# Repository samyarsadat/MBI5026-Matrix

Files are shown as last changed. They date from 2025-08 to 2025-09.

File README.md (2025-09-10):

# MBI5026 16x40 LED Display
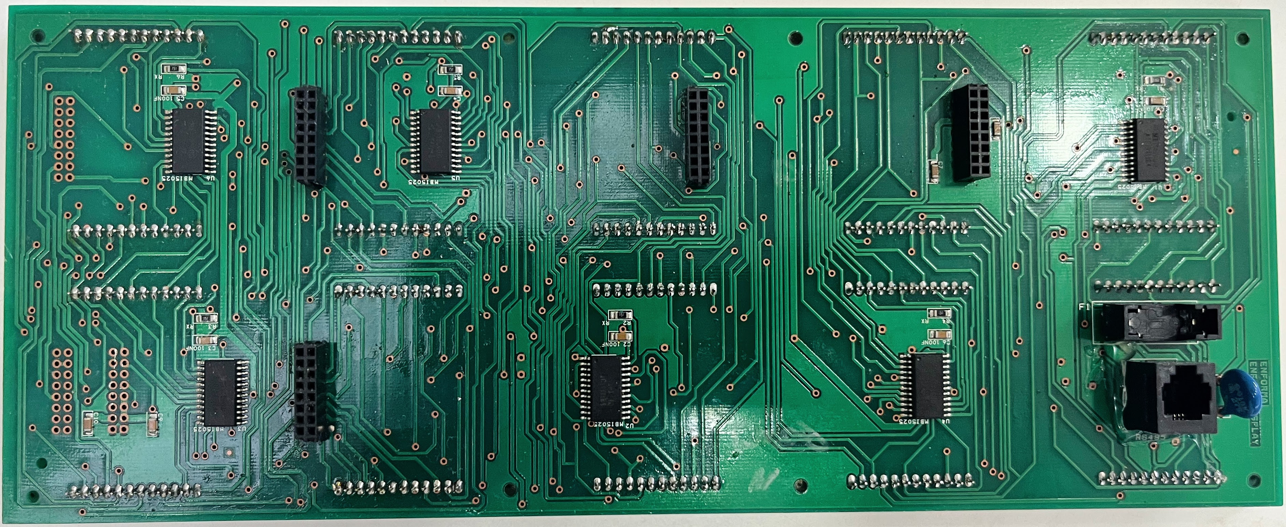
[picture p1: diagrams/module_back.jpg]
back of display module

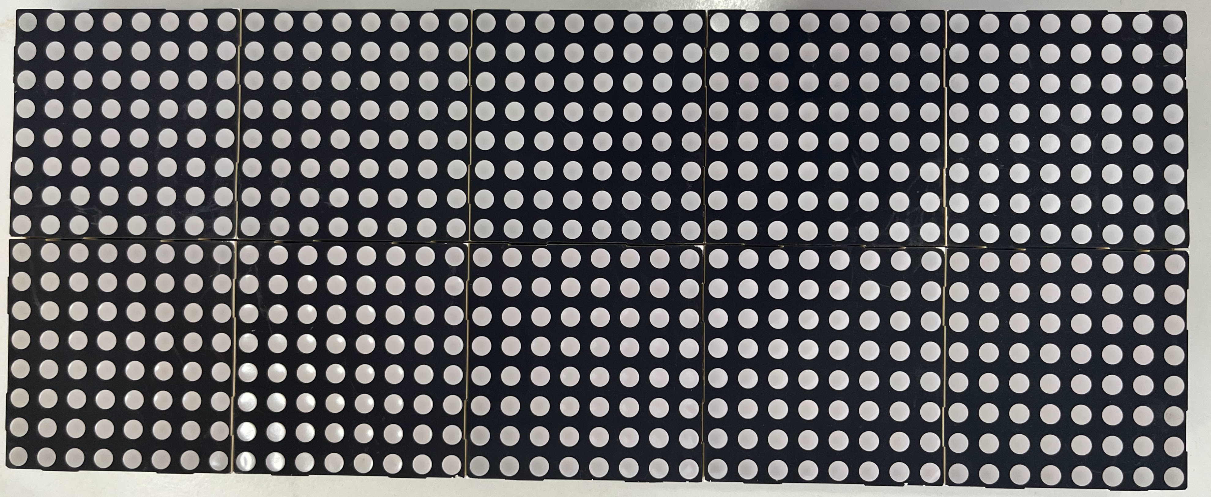
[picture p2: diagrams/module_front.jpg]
front of display module


In November 2023, I got my hands on a number of 16x40 LED matrix displays produced by a company called "Enforma". There was no documentation provided with these displays, but they had RJ-11 connectors on their backs labeled `RS485`. This gave me hope, at first, as it implied that no driver circuitry was needed and that I only needed to send data to the displays over a serial connection.

<p align="center">
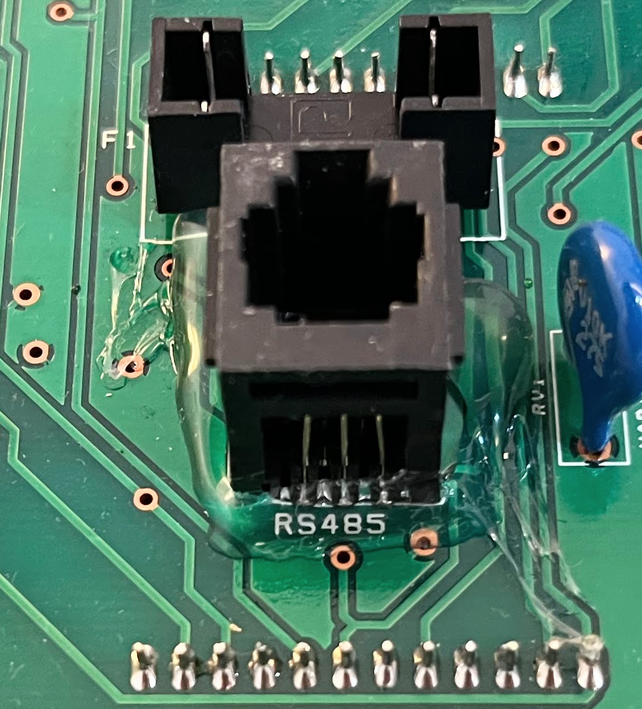
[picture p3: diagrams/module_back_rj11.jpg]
  
</p>

Upon closer inspection, I found 6 ICs on the matrix PCBs. They were all labeled `MBI5026GD`. After a quick Google search, I was able to find their datasheet. According to the datasheet, the `MBI5026` is a "16-bit constant-current LED sink driver". This tells us a lot about what these chips do, and it also indicated to me that there must be some kind of external control circuitry somewhere, but we will get to that later.

<br>

## The MBI5026
An LED sink driver (or current-sink driver) is one of two main LED driver types (the other being source/current-source drivers). Electrical current is "sunk" to these drivers, as the name might suggest (the direction of electron flow is from negative to positive, but I am referring to current flow), and so their outputs are connected to the cathodes of the LEDs. The `MBI5026`, specifically, is also a constant-current LED driver, which means that it keeps the current flowing through the LEDs constant, regardless of the LED's bias voltage (the current is set using an external resistor attached to a dedicated pin on the IC).

Another important feature of these ICs is that they handle inputs serially, similar to a shift register. This makes it rather simple for them to be daisy-chained (as they are in this matrix), and it allows for a clever optimization when it comes to sending data to them using microcontrollers. The optimization in question is using the built-in SPI hardware to send data instead of bit-banging. This allows for data to be sent at much higher rates and, of course, frees up many CPU cycles, something we need a lot of.

The LED matrix modules here are configured such that the cathodes of the LEDs are all attached to each other in columns. This means that our `MBI5026` ICs control the columns of the module. So the cathodes of all 16 LEDs in each column are connected to one output on one of the three (per color - one set for red, one set for green) `MBI5026`s.

I haven't mentioned it until now, but yes, these displays use dual-color LED matrices (red and green). That is why we have 6 `MBI5026`s instead of 3 (3 * 16 = 48 outputs, which would've been enough for a single color, as the display only has 40 columns). Each group of 3 is responsible for one color. The LEDs are wired-up as shown below:

<p align="center">
  
</p>

Okay, now we can control the columns, but what about the rows? Well... that’s where things get a little bit more complicated. I mentioned above that I initially thought no extra control circuitry was needed for the displays, but that I was mistaken. Well, let me explain why that is case.

After finding out what the `MBI5026`s were, I tried to look for some type of current-source driver for the anodes of the LEDs, but I found none. Instead, I managed to trace the anodes of the displays to a pair of headers on the back of the PCB. I then also traced two of the pins (data pins, as the other two were connected to GND and VCC) of the aforementioned RJ-11 connector to another header, and the data, clock, and latch pins of the `MBI5026`s to a fourth header.

These discoveries made it clear to me that there must have been some kind of control board attached to these display PCBs using those four connectors, and that that board contained the rest of the circuitry required for making the displays work.

<br>

## Driving the Displays
### Hardware
> [!NOTE]
> The displays are designed to operate at +5V DC, which is also the nominal operating voltage of the `MBI5026`. The operating voltage for all other components mentioned here is also +5V DC.

With all of this information in hand, I devised a simple circuit to drive these displays using the Arduino UNO R3 (ATMega328P). The circuit consists of 16 P-channel MOSFETs for driving the anodes of the matrices. As mentioned before, the anodes of the displays are linked together in rows, and these displays have 16 rows; hence, we need 16 MOSFETs.

Now, after we consider the `MBI5026` connections, we aren't left with the 16 pins we need to drive the MOSFETs, but we also don't really need 16 pins. It would be a waste to connect all MOSFETs directly, as we don't need to be able to activate more than one MOSFET at once, instead, we can use a 16-channel multiplexer.

I chose the `74HC4067`, as it's one I'm already familiar with, and it has decent specifications for this application. The `74HC4067` is a 16-channel analog multiplexer, but any 16-channel mux with good enough switching characteristics will do just fine; it doesn't even have to be an analog mux, as we're only controlling MOSFETs.

Most P-channel MOSFETs will also work just fine, you could even use PNP transistors, and you'd probably be fine. As we're multiplexing the rows, each row is only held on for around less than a millisecond (typically, depends on buffer size, and `display_row_on_delay_us`), so there is little continous current draw. The most amount of continuous current draw I observed when holding all pixels in one row on was no more than 400mA.

Note that there are 10k ohm pull-up resistors connected to the gate pins of every MOSFET to ensure that their outputs are turned off when left floating (which is the case, unless they're selected by the mux).

As mentioned before, we'll be using the Arduino's SPI hardware for sending data to the `MBI5026`s. The six `MBI5026`s are divided into two groups of three, one group for red, and the other for green. Note that the anodes for the green and red LEDs are again connected to each other, so we still only need 16 MOSFETs for driving both colors. This works because their cathodes are connected to different `MBI5026`s, of course.

As far as the cathodes are concerned, we can treat the display as two separate displays, one being the green, and the other red. But there's just one problem with this approach... the Arduino UNO R3 only has one set of SPI pins, not two (I have recently been made aware of the SPI over USART mode supported by the ATMega328P, though as you will see, that will not be necessary). The solution to this problem is quite trivial. The `MBI5026`s, in addition to their SDI (Serial Data In) and CLK (Clock) pins, also have an LE (labeled as "Data Strobe Input Terminal" in the datasheet, but I presume it stands for Latch Enable) pin.

You see, data from the input shift register isn't "committed" to the output drivers of the `MBI5026` unless a pulse is sent on the LE pin. This is very handy, as we can connect the SDI and CLK pins of both `MBI5026` groups together, but still maintain the ability to separately control both colors.

<p align="center">
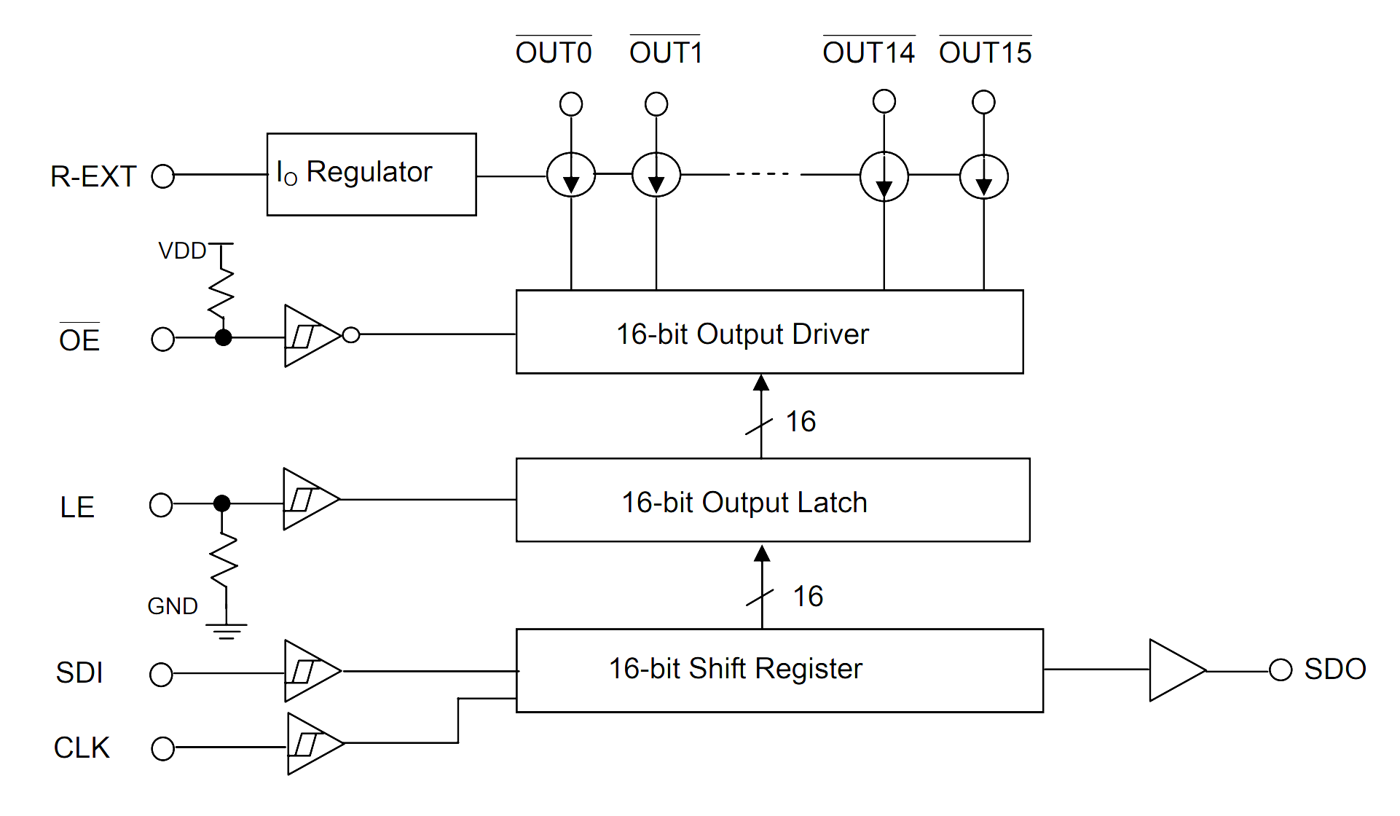
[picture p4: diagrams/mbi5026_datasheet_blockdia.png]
  
</p>

Basically, what we can do is the following:
 - Send the data for the green group over SPI.
 - Pulse the LE pin of the green group, "committing" the desired green pixel states to the output drivers.
 - Send the data for the red group over the same SPI bus.
 - Pulse the LE pin of the red group, "committing" the desired red pixel states to the output drivers.

These steps are repeated for each row, of course, as we are multiplexing the display one-row-at-a-time. More about the software implementation later on.

This is the full circuit diagram I ended up using for testing with the Arduino UNO:

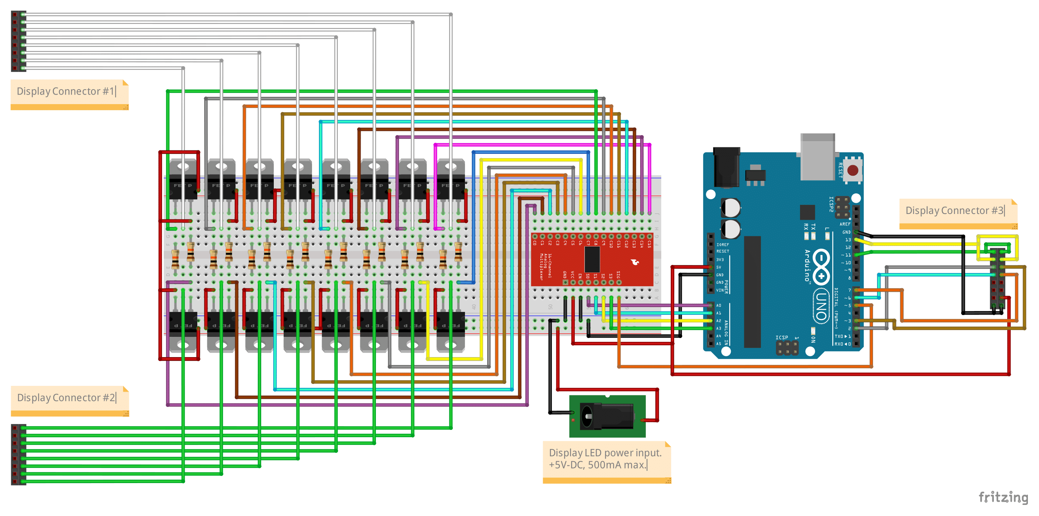
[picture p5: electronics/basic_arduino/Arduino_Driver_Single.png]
basic arduino driver circuit

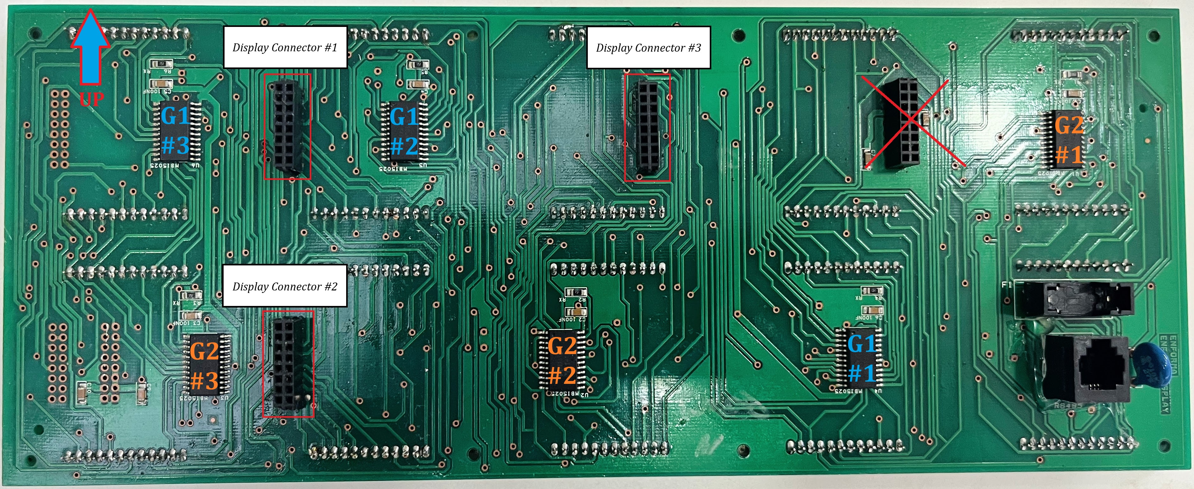
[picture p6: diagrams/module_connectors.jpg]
display module connectors


> [!WARNING]
> A small current may flow through the MOSFET pull-up resistors if the IOREF voltage (IO reference voltage, should be +5V) of the Arduino is different compared to the display LED power input voltage. To avoid this, power the Arduino from the display LED power input as well. Only do this if you don't plan on using the USB port of the Arduino, or are using a diode/MOSFET to OR the power.

> [!NOTE]
> The ground pins on connector #3 are not only logic grounds, but also sink grounds for the `MBI5026`s. Up to 500mA can flow through them (unlikely, but possible), so ensure a good connection to the LED display power supply ground.

<br>
<p align="center">
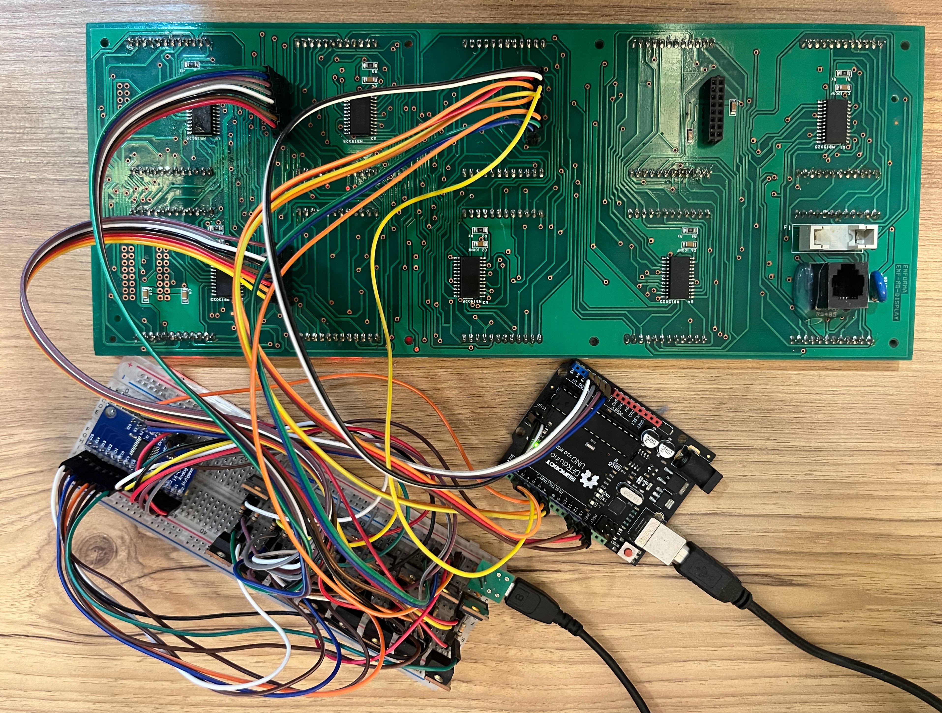
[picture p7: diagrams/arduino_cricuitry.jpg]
  
</p>

> [!NOTE]
> You may have noticed that I'm using the Arduino's ICSP header in this image. The ICSP header also exposes the SPI pins of the ATMega328P, so we can use them for the second `MBI5026` group, as it is more convenient than creating a splitter.

<br>

### Software
The software uses PlatformIO and is written in C++. I opted to use Adafruit's GFX library for text and graphics "rendering" (i.e., generating pixel data from text and/or shape drawing commands, etc.), as I saw no need to implement that myself when there's a perfectly usable and readily available implementation already.

Instead, I focused on optimizing the lower-level details of driving the displays (taking data from a set of pixel buffers, one for red and one for green, and displaying them properly). It was a rather enjoyable experience, as I got to chase down millisecond-level improvements in execution time, which is a level of optimization I often don't or can't pursue.

I will, by no means, claim to have written the _most_ optimized driver for these displays, but I certainly made an attempt, even performing direct register manipulations (I understand the portability implications this comes with, but that really does not matter here) to avoid function call overhead at some points!

In the example I've provided, all of the text "rendering" takes place during the setup phase of the program. This introduces a challenge when one tries to implement scrolling text. Re-rendering the pixel buffer on every scroll cycle is very expensive (CPU cycles-wise, and hence, time-wise) and so results in a lot of flickering.

But why would the display flicker, you may ask. Well, imagine that the pixel data is re-computed every n frames. That means that every n-frames, the frame draw function will take much longer to execute because it needs to re-compute the pixel data. This introduces a (or rather increases the already existing) gap in time where nothing is drawn on the screen, every n frames. That extra delay appears as a flicker every time the display scrolls over by one pixel.

You could simply use a more powerful microcontroller to solve this issue, such as the RP2040/RP2350 from Raspberry Pi or even a microcontroller from the STM32 series (such as the STM32F103, for example), but that would be cheating! Not that this is a competition, but still, what fun would that have been?

So I devised a rather simple solution, one that I'm sure is used in some real LED display drivers as well... We can make our display buffers longer (width-wise) than the size of our actual displays, render the entirety of the contents we want to scroll on the display once at startup (and write it to the buffers, of course), and then simply shift our view of the buffer to the right by one pixel every n-milliseconds when actually displaying the contents on the screen.

Below, you can see some diagrams explaining one full scroll cycle, as implemented right now.

<br>

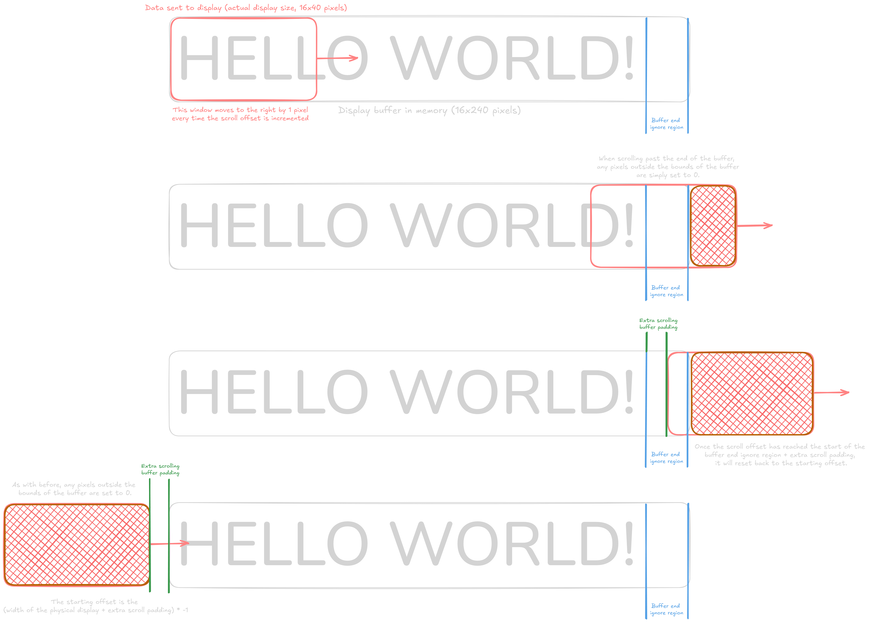
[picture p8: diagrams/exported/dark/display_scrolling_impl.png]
scrolling implementation diagram

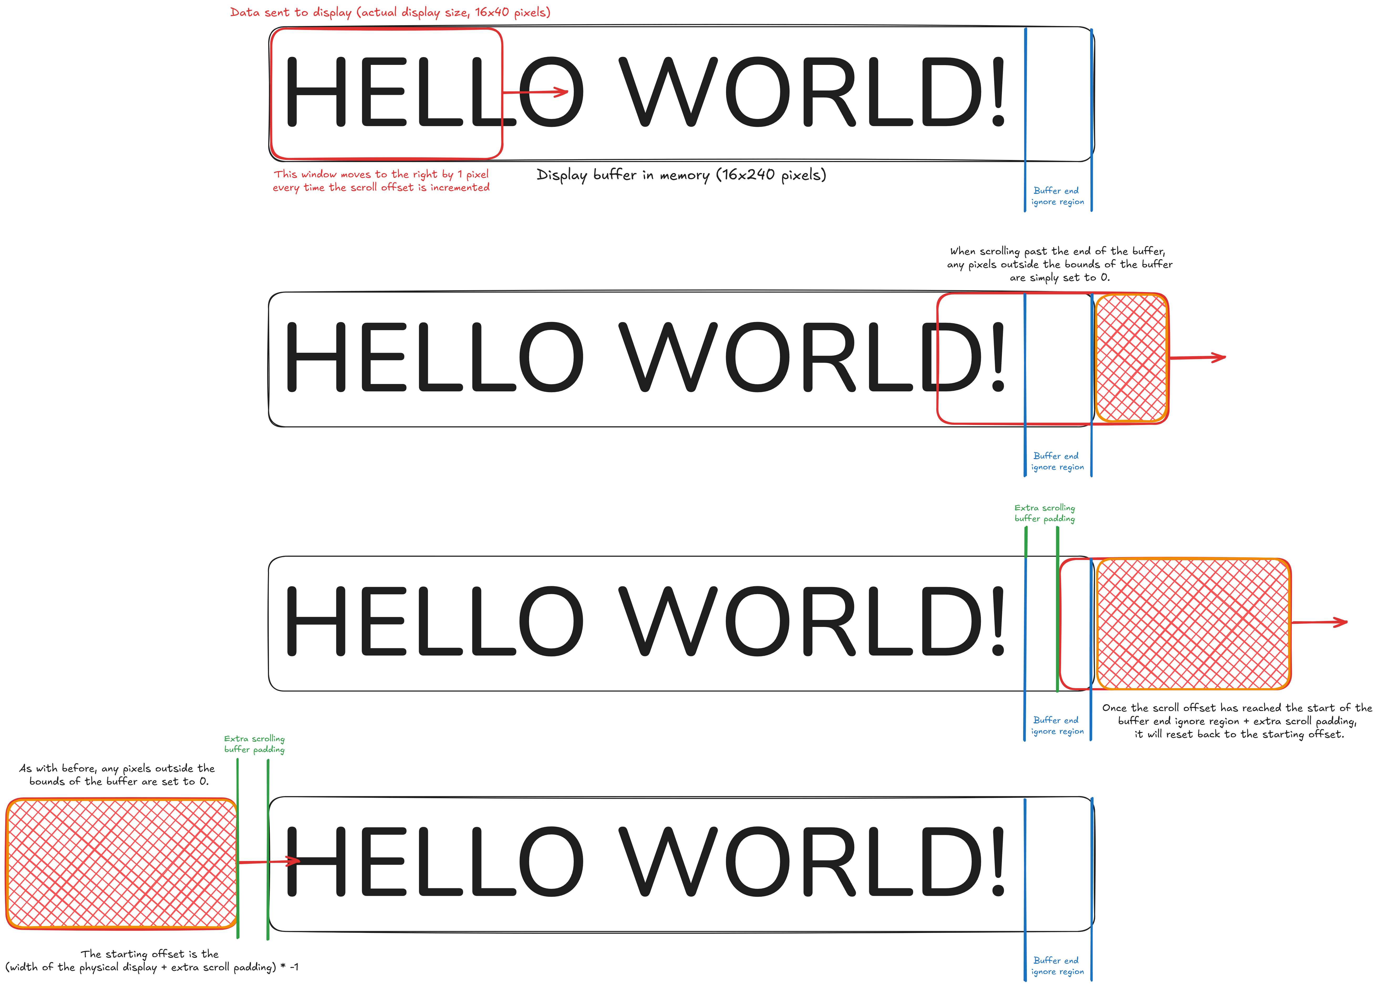
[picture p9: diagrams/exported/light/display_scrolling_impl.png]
scrolling implementation diagram


<br>

Also, the scrolling offset counter is incremented by a hardware timer interrupt. This will be important later. Oh, and if you disable scrolling (by calling `gfx_display.enableScroll(false);`), the scroll offset is ignored and only the first 40 bits (again, width-wise) of the display buffer are read and sent to the display.

> [!NOTE]
> The extra scroll padding exists to add some delay between the end of a scrolling cycle and the begining of the next one. A better way to implement this function would be to introduce a time delay between the scroll offset reaching the start of the buffer end ignore region and the scroll offset being reset to the starting offset (e.g. by having the offset increment timer wait a few cycles before resetting the scroll offset).

Now, there is _some_ extra overhead compared to just displaying a static view, but it's _significantly_ less than shifting the cursor position and re-computing the pixel data on every scroll cycle. The maximum width for our "extended buffer" is only 256 pixels, however, so whatever it is that we want to scroll must fit within those 256 pixels.

This limitation arises from the maximum limit of an unsigned 8-bit integer (255), as you may have noticed. Theoretically, we can expand the buffer beyond this by changing some variable types to 16-bit unsigned integers, and I did try this; ~~however, using 16-bit variables results in many operations taking more CPU cycles (as the ATMega328P is an 8-bit processor with 8-bit wide registers and an 8-bit ALU, and so operations that would take a single instruction with 8-bit variables take more with 16-bit ones), which results in more flickering.~~

_This is issue no longer exists in the latest firmware revision. The buffer can now be up to 255 bytes (2040 pixels) wide, though that amount won't fit into the RAM of the ATMega328P. 400 pixels seems to be around the limit of what can fit, taking into account everything else in the program._

_This has been made possible thanks to a number of major improvements and optimizations in the firmware, minimizing both the amount and impact of the extra CPU cycles needed for operations on 16-bit variables._

~~Note that the cause of this flicker is slightly different in comparison to the one mentioned [here](#display-flicker-1).~~

~~To explain why longer execution times result in flickering, I must first explain how the driver code works in greater detail. Here are the tasks performed by the program when drawing a single frame, in the order in which they are completed:~~

_This flicker can be eliminated by adjusting (reducing) `display_row_on_delay_us` in the code. I will leave this explanation of all of the tasks that are performed when drawing a single frame, as it may be useful:_
 - Interrupts are disabled to prevent the scroll offset from being incremented during a frame draw, which would result in tearing.
 - For each of the 16 rows, the following operations are repeated:
   - **[GREEN GROUP]** Read (5 * number of horizontally chained modules) bytes from the buffer into a temporary buffer, taking into account the scroll offset if scrolling is enabled.
   - **[RED GROUP]** Same as above, but for the red group.
   - Disable both `MBI5026` groups (`OE`s set high), turning the currently active row off (the previous row, unless the current row is 0, in which case it would be the last row).
   - Set the mux output address to the address of our current row (the address determines which one of the 16 channels is connected through to the mux's IO pin).
   - Send the previously read bytes from the temporary **GREEN** buffer to the `MBI5026`s over SPI.
   - **[GREEN GROUP]** Pulse the latch pin, committing the data we just sent to the output buffers of the `MBI5026`s for this group.
   - **[GREEN GROUP]** Enable the `MBI5026`s by setting the `OE` pin low.
   - Send the previously read bytes from the temporary **RED** buffer to the `MBI5026`s over SPI.
   - **[RED GROUP]** Pulse the latch pin, committing the data we just sent to the output buffers of the `MBI5026`s for this group.
   - **[RED GROUP]** Enable the `MBI5026`s by setting the `OE` pin low.
   - Wait for 850 microseconds. If we don't wait here, the program will continue to the next iteration of the loop immediately, turning off the row we just turned on, which would make the display very dim for obvious reasons.
 - Enable interrupts again to allow for the scroll counter to be incremented by the timer ISR.

Now, as you can see, we have to retrieve data from the buffers when drawing each row. ~~The variables we would have to change for extending the buffer would affect this operation. Another important fact is that all LEDs are held off as data is retrieved from the buffers and sent to the display.~~

~~The extra time it takes to retrieve and send data for each row results in the LEDs being off for longer as each row is drawn, which appears as flickering.~~

Now, we can decrease `display_row_on_delay_us` (the time for which the LEDs of each row are held on) so that rows take less time to draw, which will help alleviate this flickering to a certain degree, but it will also make the display much dimmer.

~~Thinking about it now, in retrospect, this issue might be resolvable. If we keep the pervious row on while retrieving data for the current row and only turn the previous row off before sending data to the `MBI5026`s, the LEDs won't be held off for as long. Now, row draws will still take longer, but at least the LED on-time percentage will be higher, which might allow us to decrease `display_row_on_delay_us` without sacrificing much brightness. I have not tried this yet though.~~

_After testing, I have found that keeping the previous row on while data for the current row is being retrieved improves flickering, as well as perceived display brightness. This allows us to adjust (reduce) `display_row_on_delay_us` to compensate for the extra time that it may take for data to be read from the display buffers without sacrificing much brightness and reducing display flicker to negligible levels._

In the above explanation, I state that 5 bytes of data are sent to the `MBI5026`s for every row (per module). This is not completely true. As you may know, each `MBI5026` has 16 outputs, and so would logically require 2 bytes of data (16 / 8 = 2 bytes); however, our display is 40 pixels wide, which would only require 5 bytes of data (40 / 8 = 5 bytes). Now, because 40 isn't a multiple of 16, 8 channels of one of the `MBI5026`s remain unconnected.

So whilst only 5 bytes of data is actually used for each row, in reality, we must send an extra, empty byte to fill the shift register bits of the unconnected 8 channels. This empty byte is the first byte sent, as the unconnected channels on this display are the last 8 channels of the first `MBI5026`, which corresponds to the first byte of data sent (data in the shift register is propagated from last to first).

<br>

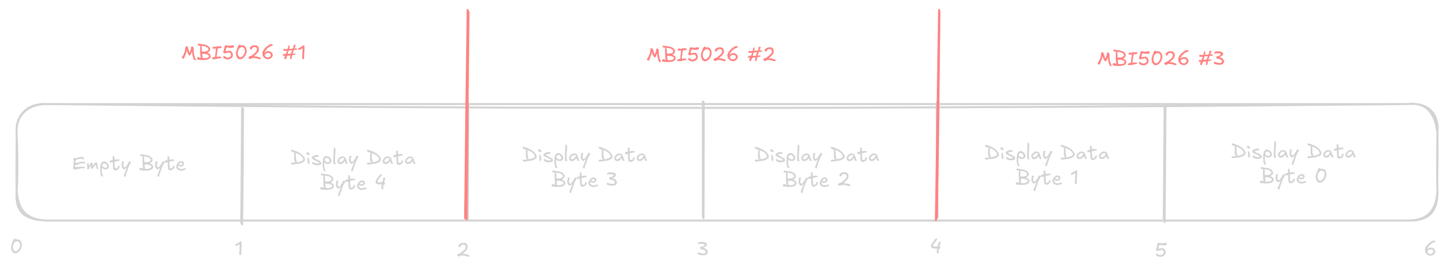
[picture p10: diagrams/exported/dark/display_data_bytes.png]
display data bytes

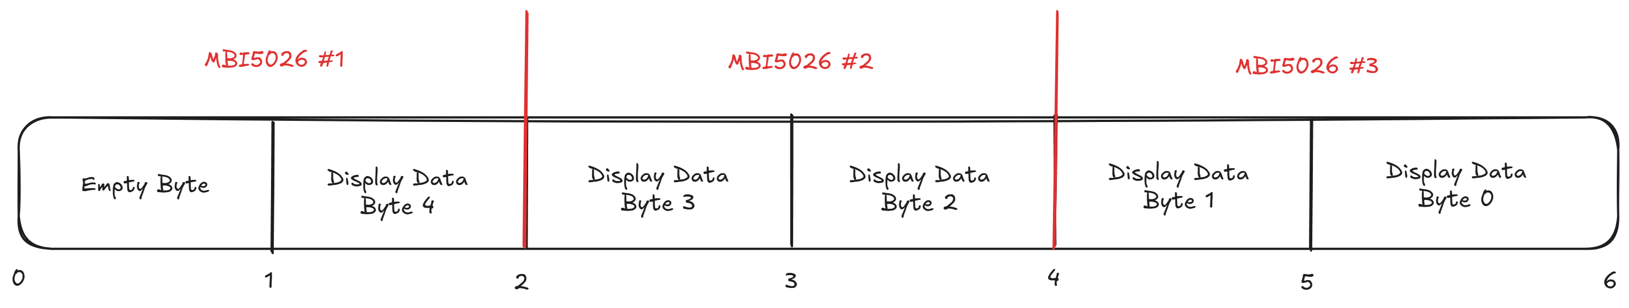
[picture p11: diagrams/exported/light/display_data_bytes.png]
display data bytes


<br>

And just as a side note, daisy-chaining of `MBI5026`s is possible because of how shift registers work (the `MBI5026` is just a shift register with some extra circuitry for driving LEDs). When a pulse is sent over their clock pin, they shift all of the bits currently in the register over by one position and fill their first bit (which is emptied as a result of the shift) with whatever is on the Data In pin when the pulse is received (either a 1 or a 0). And what happens to the last bit in the shift register? Well, it gets shifted to the Data Out pin, where it can be shifted on to the first bit of the next shift register in line (assuming that the Data Out pin is connected to the Data In pin of another shift register and that they share a clock pin).

<br>

## Driving More Than One Display
Given all of the information I have presented until now, it should be very easy for someone to implement code for driving more than one of these displays at once (i.e., dasiy-chaining them vertically or horizontally); however, I would still like to explain how I would do it if I were to implement this, as I have given it some thought.

<br>

### Horizontal Daisy-Chaining
Horizontally daisy-chaining these displays is quite trivial. All you need to do is solder a wire to the SDO (Serial Data Out) pins of the last `MBI5026`s on the first display (for both green and red groups) and then attach that wire to the SDI (Serial Data In) of the next display module (you also have to connect the CLK pins together). And for the anodes, you can connect them to the same MOSFETs as with the first display module (i.e., row 1 anode to MOSFET 1, row 2 anode to MOSFET 2, etc., just like the first display module).

<br>

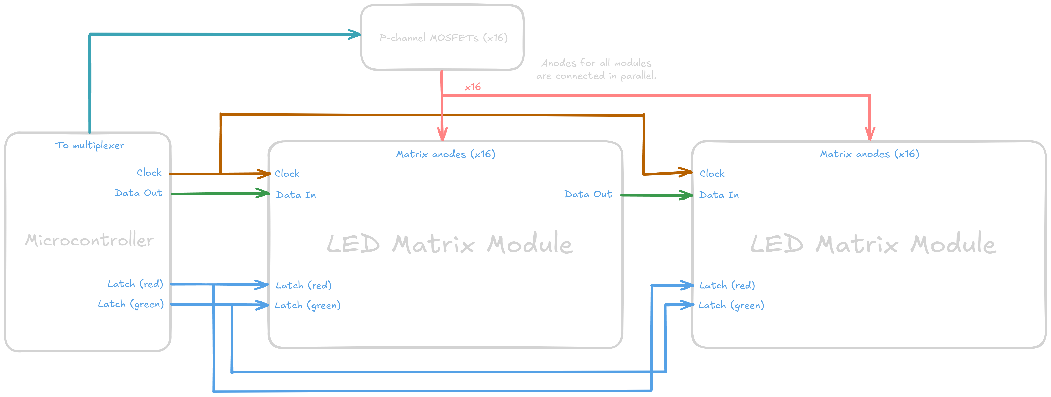
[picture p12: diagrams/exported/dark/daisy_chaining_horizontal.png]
horizontal daisy-chaining diagram

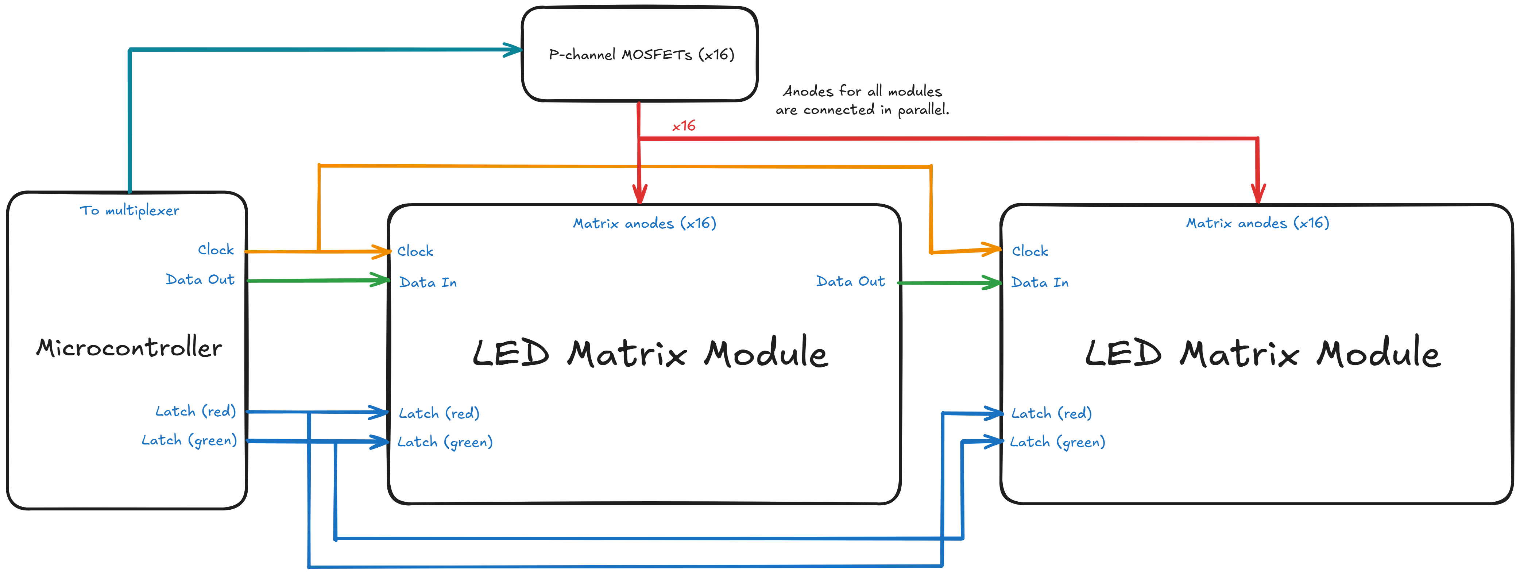
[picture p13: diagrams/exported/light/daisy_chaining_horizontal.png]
horizontal daisy-chaining diagram


<br>

And of course, in the code you must send 12 bytes of data to the `MBI5026`s instead of 6 (10 effective data bytes instead of 5), ~~and unless you extend the buffer, you can only daisy-chain up to 6 display modules (with 16 pixels to spare) because of the 256-bit buffer width limit.~~

Also note that the more data has to be read and sent, the more CPU cycles are required, so your mileage may vary in terms of the flickering and display performance. You must also take into consideration the current limit of your MOSFETs when adding additional display modules.

<br>

### Vertical Daisy-Chaining
In terms of electrical connections, vertical daisy-chaining is identical to horizontal daisy-chaining, with the only difference being that the displays are physically stacked on top of one another instead of being placed next to each other.

<br>

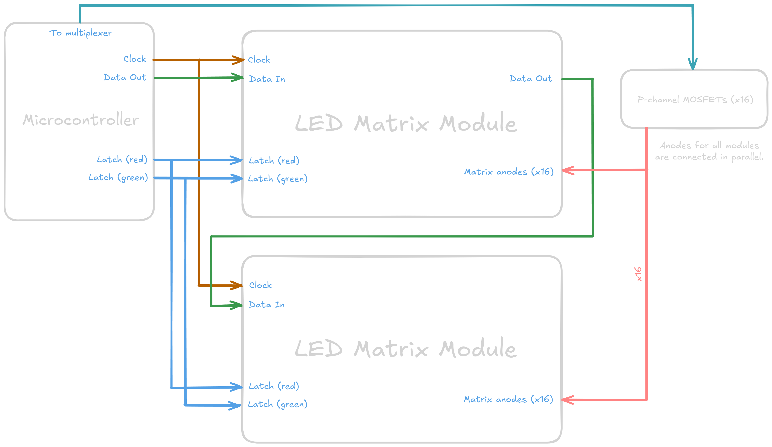
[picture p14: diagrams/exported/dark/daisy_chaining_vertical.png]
vertical daisy-chaining diagram

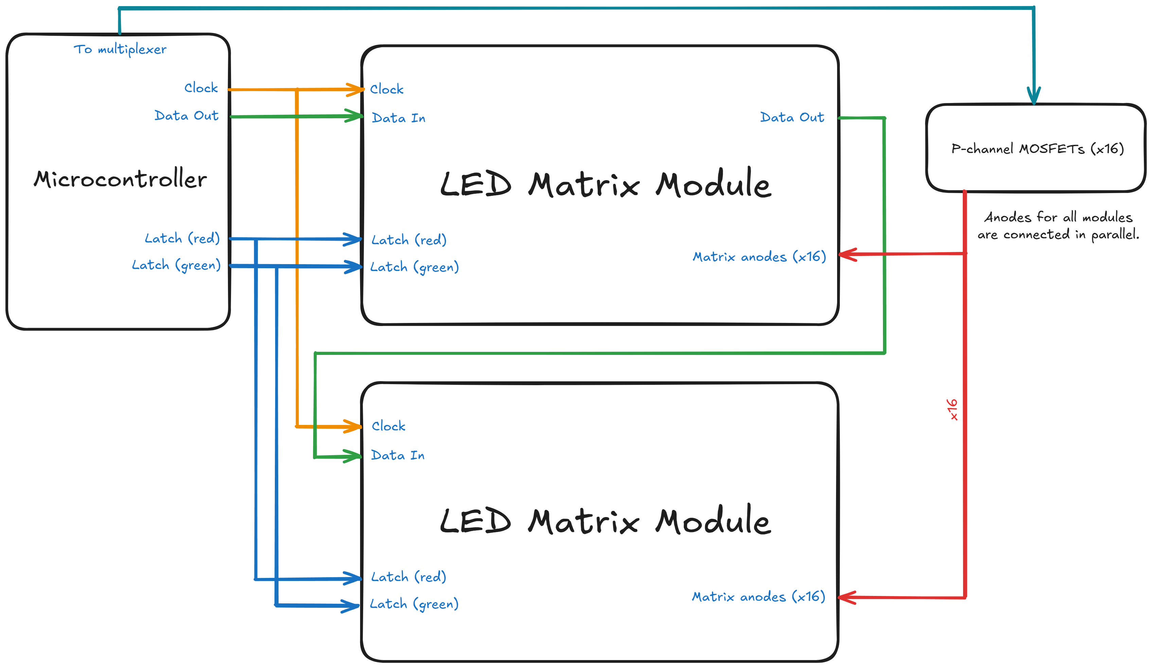
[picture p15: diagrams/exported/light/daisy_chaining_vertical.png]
vertical daisy-chaining diagram


<br>

The only difference is in the software. You have to make sure that the first 5 bytes of data sent are for the first row of the first module, and the second 5 bytes for the first row of the second module, and so on (ignoring the empty bytes here), and you must extend the display buffers vertically (or interleave the data and store it in a single, 16-pixel high buffer. The exact implementation is a matter of taste).

<br>

### What About Both?
You can combine these techniques to daisy-chain as many displays as you want, both vertically and horizontally, assuming you have sufficiently large display buffers and a sufficiently performant microcontroller.

<br>

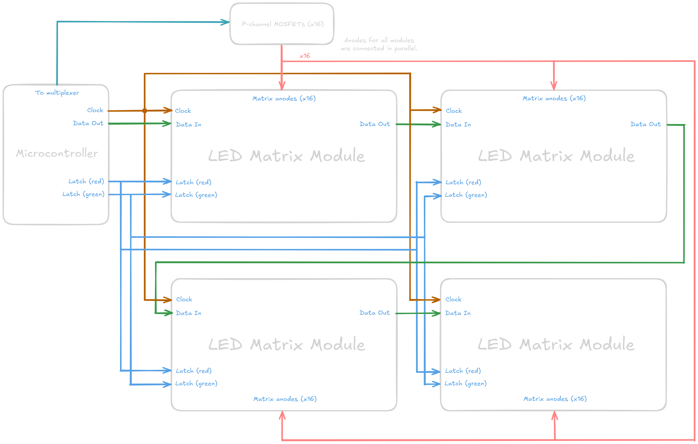
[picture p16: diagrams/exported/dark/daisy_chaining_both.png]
vertical & horizontal daisy-chaining diagram

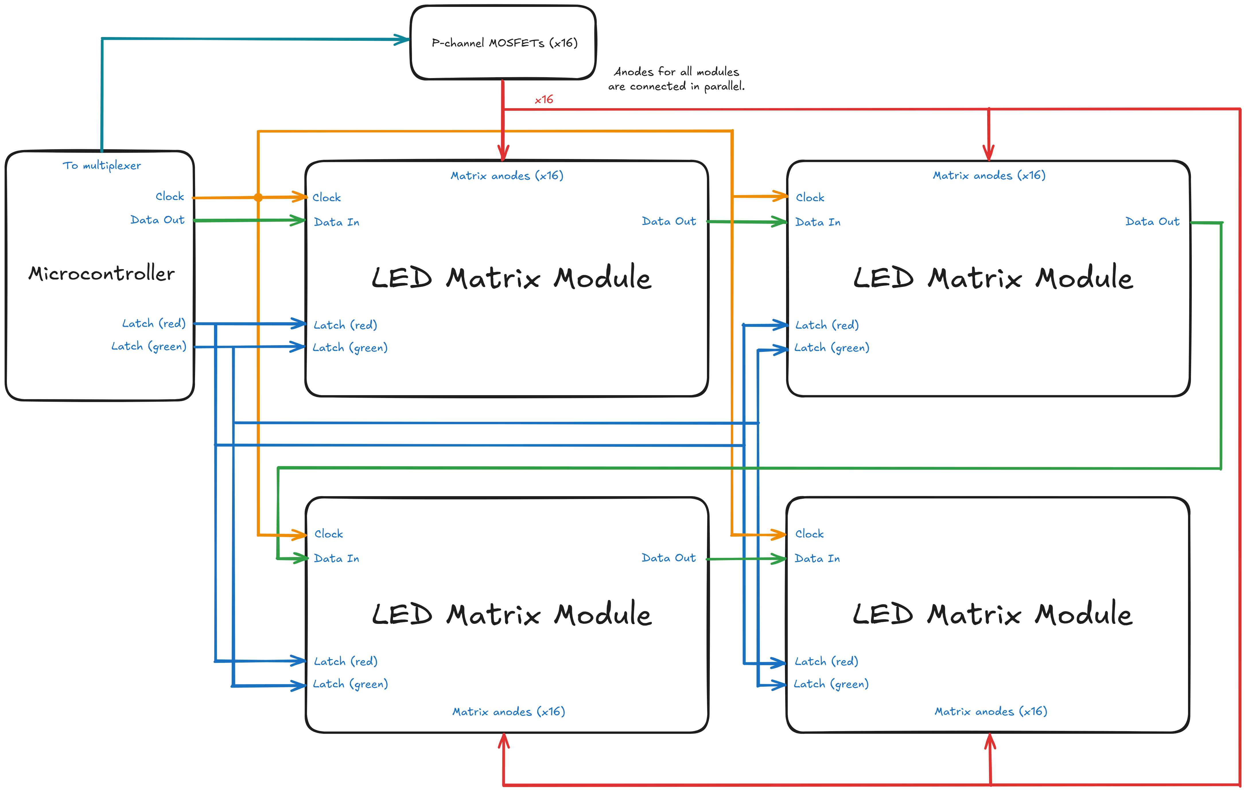
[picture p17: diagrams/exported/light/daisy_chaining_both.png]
vertical & horizontal daisy-chaining diagram


<br>

You could, of course, use multiple SPI busses to send data to each row independently, or use multiple sets of MOSFETs, etc. There are many different possible configurations. The ones provided here are the simplest, most basic ones.

<br>

## Contact
If you have any further questions, you can contact me directly at [samyarsadat@gigawhat.net](mailto:samyarsadat@gigawhat.net) or [open a GitHub issue](../../issues).

<br>

Copyright © 2025 Samyar Sadat Akhavi.\
Written by Samyar Sadat Akhavi, 10/09/2025.

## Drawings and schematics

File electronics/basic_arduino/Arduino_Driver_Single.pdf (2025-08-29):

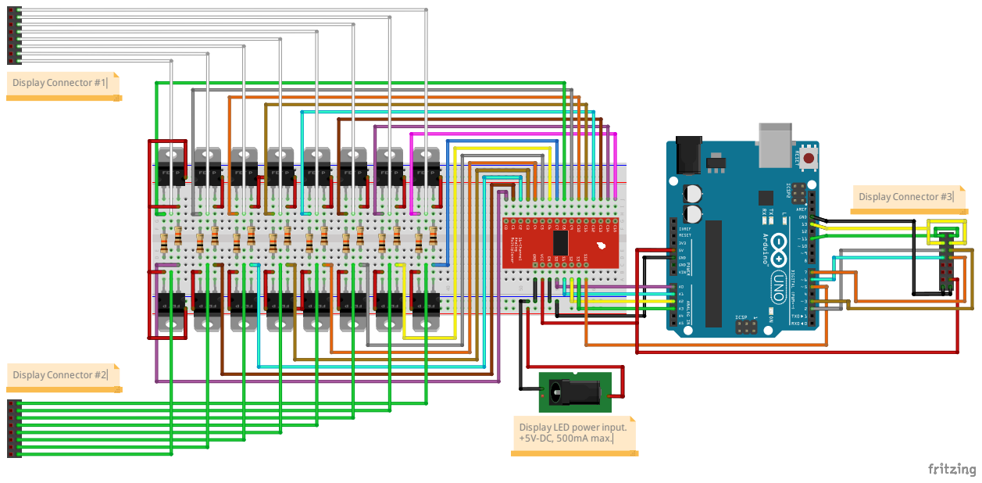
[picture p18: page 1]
Display Connector #1; Display Connector #2; Display Connector #3

Display LED powerinput.
+5V-DC, 500mA max.

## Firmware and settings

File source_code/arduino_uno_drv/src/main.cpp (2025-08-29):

/*
    MBI5026 16x40 LED Dual-color Matrix Display
    Driver code for Arduino UNO R3

    Copyright 2025 Samyar Sadat Akhavi
    Written by Samyar Sadat Akhavi, 2025.

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
    You should have received a copy of the GNU General Public License
    along with this program.  If not, see <https: www.gnu.org/licenses/>.
*/

// Libraries
#include "Arduino.h"
#include <SPI.h>
#include "Adafruit_GFX.h"


// ---- Definitions ----
// Pins
#define ps_mux_sig_pin      PD5
#define ns_drv_grn_lat_pin  PD3
#define ns_drv_grn_en_pin   PD7
#define ns_drv_red_lat_pin  PD2
#define ns_drv_red_en_pin   PD6

// Display config
#define display_height               16    // Pixels
#define display_width                40    // Pixels
#define display_row_on_delay_us      400   // Microseconds, feel free to experiment with this value
#define x_scroll_extra_buff_padding  10    // Pixels (MAX. 15, will cause overflow)

// If wired as shown in README.md, you can adjust this value to daisy-chain displays horizontally. 
// Everything else will work out-of-the-box (I have tested it). If 10 is not divisible by this number,
// consider adjusting buffer_width_multiplier manually. display_modules_chained * buffer_width_multiplier
// shouldn't be higher than 10, as it may not fit into RAM, or cause a stack overflow at runtime.
#define display_modules_chained   1
#define buffer_width_multiplier   (10 / display_modules_chained)

// Scroll timer
#define scroll_timer_prescale  B00000101

// SPI config
#define spi_clk_frequency  8000000   // 8 MHz (max for ATMega328P @ 16 MHz, though MBI5026 can do 25 MHz)

// GFX color definitions
#define BLACK   0
#define RED     1
#define GREEN   2
#define ORANGE  3


// ---- Global variables ----
constexpr uint8_t num_disp_data_bytes = display_modules_chained * 6;                     // Number of total data bytes
constexpr uint8_t num_pixel_data_bytes = num_disp_data_bytes - display_modules_chained;  // Number of bytes for pixel data, ignoring the first empty byte.
constexpr uint8_t buffer_width_bytes = num_pixel_data_bytes * buffer_width_multiplier;
constexpr uint16_t buffer_width_pixels = buffer_width_bytes * 8;

// Display buffers
uint8_t green_buffer[buffer_width_bytes][display_height] = {0};
uint8_t red_buffer[buffer_width_bytes][display_height] = {0};

// Temporary display row data buffers
uint8_t row_buffer_grn[num_disp_data_bytes] = {0};
uint8_t row_buffer_red[num_disp_data_bytes] = {0};

// Scrolling
constexpr int16_t scroll_buffer_starting_offset = ((display_width * display_modules_chained) + x_scroll_extra_buff_padding) * -1;
uint16_t x_scroll_offset_max = buffer_width_pixels + x_scroll_extra_buff_padding;
volatile int16_t x_scroll_offset = 0;
uint16_t scroll_timer_comp_val = 800;
bool scroll_enabled = false;


// ---- Buffer bit helpers ----
inline __attribute__((always_inline))
void set_buffer_bit(uint8_t (*buffer)[display_height], const uint16_t x, const uint8_t y, const bool state) {
  const uint8_t x_buffer_num = x >> 3;

  if (state) {
    buffer[x_buffer_num][y] = buffer[x_buffer_num][y] | (1u << (x & 7));
  } else {
    buffer[x_buffer_num][y] = buffer[x_buffer_num][y] & ~(1u << (x & 7));
  }
}

inline __attribute__((always_inline))
bool get_buffer_bit(const uint8_t (*buffer)[display_height], const uint16_t x, const uint8_t y) {
  return (buffer[x >> 3][y] >> (x & 7)) & 1;
}


// ---- Prototypes for buffer row reading functions ----
void read_row_data_static(const uint8_t (*buffer)[display_height], uint8_t* row_buffer, const uint8_t row_num);
void read_row_data_scrolling(const uint8_t (*buffer)[display_height], uint8_t* row_buffer, const uint8_t row_num);

// Buffer row data retrieval function
typedef void (*read_buffer_row_func_t)(const uint8_t (*buffer)[display_height], uint8_t* row_buffer, const uint8_t row_num);
read_buffer_row_func_t read_buffer_row = read_row_data_static;


// ---- GFX class ----
class DisplayMatrix : public Adafruit_GFX {
  public:
    DisplayMatrix() : Adafruit_GFX(buffer_width_pixels, display_height) {}

    void drawPixel(const int16_t x, const int16_t y, const uint16_t color) override {
      if (x < 0 || x > static_cast<int16_t>(buffer_width_pixels - 1) || y < 0 || y > (display_height - 1)) {
        return;
      }

      const uint8_t y_inverted = (display_height - 1) - y;

      switch (static_cast<uint8_t>(color)) {
        case RED:
          set_buffer_bit(red_buffer, x, y_inverted, true);

          if (get_buffer_bit(green_buffer, x, y_inverted))
            set_buffer_bit(green_buffer, x, y_inverted, false);
          break;
        case GREEN:
          set_buffer_bit(green_buffer, x, y_inverted, true);

          if (get_buffer_bit(red_buffer, x, y_inverted))
            set_buffer_bit(red_buffer, x, y_inverted, false);
          break;
        case ORANGE:
          set_buffer_bit(red_buffer, x, y_inverted, true);
          set_buffer_bit(green_buffer, x, y_inverted, true);
          break;
        default:
          set_buffer_bit(red_buffer, x, y_inverted, false);
          set_buffer_bit(green_buffer, x, y_inverted, false);
          break;
      }
    }

    void fillScreen(const uint16_t color) override {
      switch (static_cast<uint8_t>(color)) {
        case RED:
          memset(red_buffer, 0xFF, sizeof(red_buffer));
          memset(green_buffer, 0, sizeof(green_buffer));
          break;
        case GREEN:
          memset(red_buffer, 0, sizeof(red_buffer));
          memset(green_buffer, 0xFF, sizeof(green_buffer));
          break;
        case ORANGE:
          memset(red_buffer, 0xFF, sizeof(red_buffer));
          memset(green_buffer, 0xFF, sizeof(green_buffer));
          break;
        default:
          memset(red_buffer, 0, sizeof(red_buffer));
          memset(green_buffer, 0, sizeof(green_buffer));
          break;
      }
    }

    void clearDisplay() {
      setCursor(0, 0);
      fillScreen(BLACK);
    }

    void enableScroll(const bool enable) {
      scroll_enabled = enable;

      if (enable) {
        x_scroll_offset = scroll_buffer_starting_offset;
        read_buffer_row = read_row_data_scrolling;
      } else {
        x_scroll_offset = 0;
        read_buffer_row = read_row_data_static;
      }
    }

    void setScrollSpeed(const uint8_t speed) {
      const uint16_t speed_scaled = map(speed, 0, 255, 6000, 315);
      scroll_timer_comp_val = speed_scaled;
      OCR1A = speed_scaled;
    }

    void setEndBufferIgnore(const uint16_t pixels) {
      if (pixels <= buffer_width_pixels + x_scroll_extra_buff_padding) {
        x_scroll_offset_max = buffer_width_pixels + x_scroll_extra_buff_padding - pixels;
      }
    }
};

DisplayMatrix gfx_display;


// ---- Functions ----
// Extract byte from buffer with bit offset
inline __attribute__((always_inline))
uint8_t extract_byte(const uint8_t (*buffer)[display_height], const uint8_t row_num, const int16_t bit_offset) {
  const int16_t byte_idx = bit_offset >> 3;
  const uint8_t bit_shift = static_cast<uint8_t>(bit_offset & 7);

  const uint8_t byte_lo = (byte_idx >= 0 && byte_idx < buffer_width_bytes) ? buffer[byte_idx][row_num] : 0;
  if (bit_shift == 0) return byte_lo;

  const uint8_t byte_hi = (byte_idx + 1 >= 0 && byte_idx + 1 < buffer_width_bytes) ? buffer[byte_idx + 1][row_num] : 0;
  return static_cast<uint8_t>((byte_lo >> bit_shift) | (byte_hi << (8 - bit_shift)));
}

// General buffer and I/O helper
inline __attribute__((always_inline))
void read_row_data_scrolling(const uint8_t (*buffer)[display_height], uint8_t* row_buffer, const uint8_t row_num) {
  uint8_t byte_num = num_pixel_data_bytes;
  uint8_t i = 0;

  while (i < num_disp_data_bytes) {
    row_buffer[i++] = 0x00;  // First byte of data sent to each display module is ignored.

    for (uint8_t j = 0; j < 5; j++, i++) {
      row_buffer[i] = extract_byte(buffer, row_num, (--byte_num << 3) + x_scroll_offset);
    }
  }
}

// Non-scrolling variant of read_row_data(). Slightly faster.
inline __attribute__((always_inline))
void read_row_data_static(const uint8_t (*buffer)[display_height], uint8_t* row_buffer, const uint8_t row_num) {
  uint8_t byte_num = num_pixel_data_bytes;
  uint8_t i = 0;

  while (i < num_disp_data_bytes) {
    row_buffer[i++] = 0x00;  // First byte of data sent to each display module is ignored.

    for (uint8_t j = 0; j < 5; j++, i++) {
      row_buffer[i] = buffer[--byte_num][row_num];
    }
  }
}

// Frame drawing
void draw_frame() {
  noInterrupts();

  for (uint8_t i = 0; i < display_height; i++) {
    read_buffer_row(green_buffer, row_buffer_grn, i);
    read_buffer_row(red_buffer, row_buffer_red, i);

    PIND = (1 << ns_drv_grn_en_pin);      // Disable both colors
    PIND = (1 << ns_drv_red_en_pin);
    PORTC = (PORTC & 0xF0) | (i & 0x0F);  // Set mux address pins

    // Send green data
    SPIClass::transfer(row_buffer_grn, num_disp_data_bytes);
    PIND = (1 << ns_drv_grn_lat_pin);
    PIND = (1 << ns_drv_grn_lat_pin);
    PIND = (1 << ns_drv_grn_en_pin);   // Enable green channel

    // Send red data
    SPIClass::transfer(row_buffer_red, num_disp_data_bytes);
    PIND = (1 << ns_drv_red_lat_pin);
    PIND = (1 << ns_drv_red_lat_pin);
    PIND = (1 << ns_drv_red_en_pin);   // Enable red channel

    delayMicroseconds(display_row_on_delay_us);
  }

  interrupts();
}

// Timer1 CompA callback (scroll timer)
ISR(TIMER1_COMPA_vect) {
  OCR1A += scroll_timer_comp_val;

  if (scroll_enabled) {
    x_scroll_offset ++;

    if (x_scroll_offset == static_cast<int16_t>(x_scroll_offset_max)) {
      x_scroll_offset = scroll_buffer_starting_offset;
    }
  }
}


// ---- Main program functions ----
void setup() {
  // Mux address pins
  pinMode(A0, OUTPUT);
  pinMode(A1, OUTPUT);
  pinMode(A2, OUTPUT);
  pinMode(A3, OUTPUT);

  pinMode(ps_mux_sig_pin, OUTPUT);
  pinMode(ns_drv_red_lat_pin, OUTPUT);
  pinMode(ns_drv_red_en_pin, OUTPUT);
  pinMode(ns_drv_grn_lat_pin, OUTPUT);
  pinMode(ns_drv_grn_en_pin, OUTPUT);

  digitalWrite(ps_mux_sig_pin, LOW);
  digitalWrite(ns_drv_red_lat_pin, LOW);
  digitalWrite(ns_drv_red_en_pin, LOW);
  digitalWrite(ns_drv_grn_lat_pin, LOW);
  digitalWrite(ns_drv_grn_en_pin, LOW);

  SPIClass::begin();
  SPIClass::beginTransaction(SPISettings(spi_clk_frequency, MSBFIRST, SPI_MODE0));

  // Timer setup
  TCCR1A = 0;
  TCCR1B = 0;
  TCCR1B |= scroll_timer_prescale;
  OCR1A = scroll_timer_comp_val;
  TIMSK1 |= B00000010;

  gfx_display.enableScroll(true);
  gfx_display.setTextSize(2, 2);
  gfx_display.setTextWrap(false);
  gfx_display.clearDisplay();
  gfx_display.setCursor(0, 1);
  gfx_display.setTextColor(RED);
  gfx_display.print("THIS IS A VERY LONG ");
  gfx_display.setTextColor(GREEN);
  gfx_display.print("TEST MESSAGE!");
  gfx_display.setScrollSpeed(255);

  int16_t unused_i;
  uint16_t unused_u, text_width;
  gfx_display.getTextBounds("THIS IS A VERY LONG TEST MESSAGE!", 0, 1, &unused_i, &unused_i, &text_width, &unused_u);
  gfx_display.setEndBufferIgnore(buffer_width_pixels - text_width + 1);
}

void loop() {
  // Preferably do not put ANYTHING ELSE in the main loop.
  // draw_frame() must be called consistently, with no delays.
  // Use timer interrupts for repeating tasks. Though interrupt callbacks
  // must also not take too long to execute.
  draw_frame();
}

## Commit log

2025-08-29 Added diagram files.
    [Arduino_Driver_Single.fzz]
2025-08-29 Significant improvements to driver firmware.
2025-08-29 Fixed incorrect code comment.
    [main.cpp]

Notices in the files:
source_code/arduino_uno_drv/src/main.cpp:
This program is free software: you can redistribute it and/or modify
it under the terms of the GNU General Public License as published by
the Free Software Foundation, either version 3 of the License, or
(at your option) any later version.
